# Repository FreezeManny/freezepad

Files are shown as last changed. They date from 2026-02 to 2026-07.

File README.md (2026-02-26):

# Freezepad

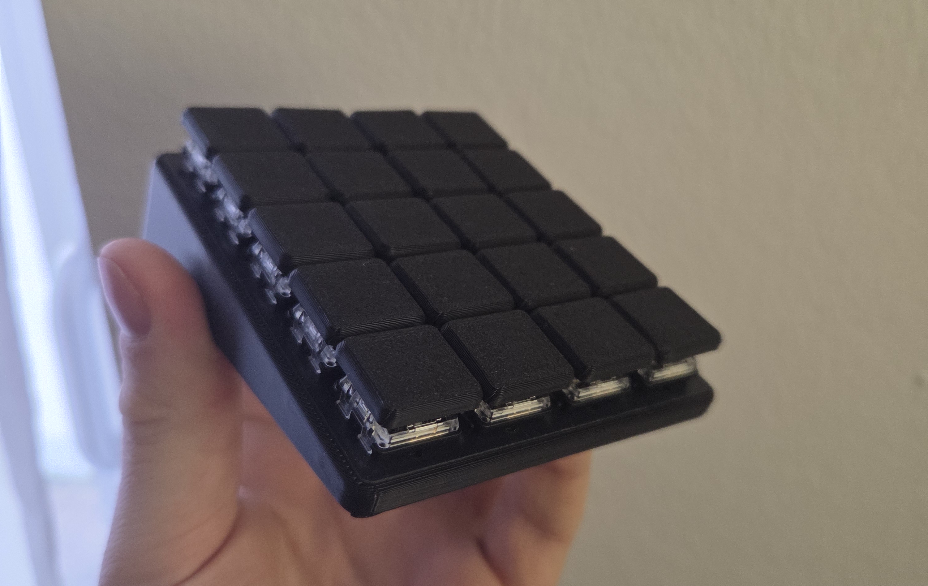
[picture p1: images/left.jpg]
Left

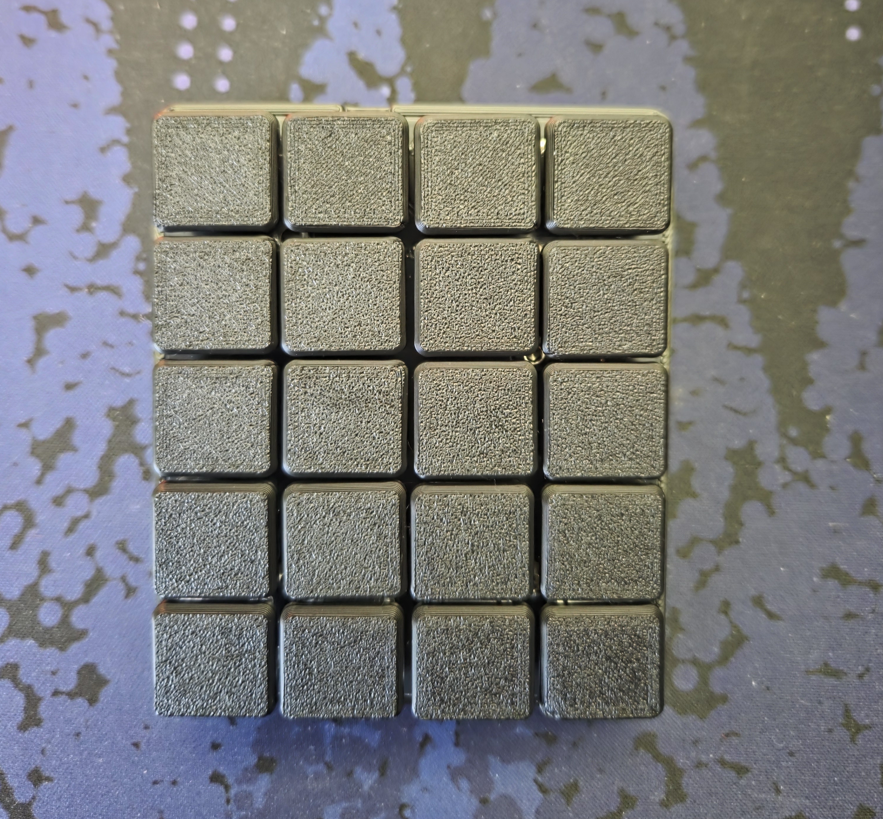
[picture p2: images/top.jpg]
Top


This repository contains all files and configuration for the **Freezepad**, a custom wireless 20-key (5×4) low-profile macropad built completely from scratch. The goal was to create the smallest possible macropad footprint — achieved by placing the Nice!Nano v2 controller directly below the switches and eliminating diodes entirely. It runs ZMK firmware and is housed in a custom 3D printed case.

## Table of Contents

- [Hardware Components](#hardware-components)
- [PCB](#pcb)
- [Firmware (ZMK)](#firmware-zmk)
- [3D Printed Case](#3d-printed-case)
- [Build Notes](#build-notes)

---

## Hardware Components

| Component | Item | Notes |
| :--- | :--- | :--- |
| **PCB** | Custom Freezepad PCB | Ordered from JLCPCB. Files in `/pcb/`. |
| **Small Electronics** | 1x Push Button 6x2mm, 20x Kailh Choc V1 Hotswap Sockets, 1x Battery Switch | Ordered from AliExpress. |
| **Small Case Parts** | 3x M3 Heat Insert, 3x M3 Screw | For securing the PCB to the case. |
| **Controller** | 1x Nice!Nano v2 (or compatible) | Wireless connectivity via Bluetooth. |
| **Battery** | 1x 102050 LiPo (1000mAh) | Fits in the custom case. |
| **Switches** | 20x Kailh Choc V1 | e.g., Sunset, Robins. |
| **Keycaps** | 20x Choc V1 Keycaps | e.g., MBK Blank Choc Keycaps. |
| **Case** | Custom 3D Printed Case | Files are located in the `/case` directory. |

---

## PCB

The custom PCB was designed using Ergogen. The files are located in the `/pcb/` directory.

---

## Firmware (ZMK)

The Freezepad runs on [ZMK Firmware](https://zmk.dev/docs), designed for wireless keyboards and macropads.

### Configuration

* **ZMK Config:** The main configuration files are located in the `/config/` directory.

### Configure, Build & Flash

* **Configuration:** Use the [Keymap Editor](https://nickcoutsos.github.io/keymap-editor/)
* **Build:** Standard GitHub Actions (see `build.yaml`)
* **Flash:** Consult the [Nice!Nano documentation](https://nicekeyboards.com/docs/nice-nano/)

---

## 3D Printed Case

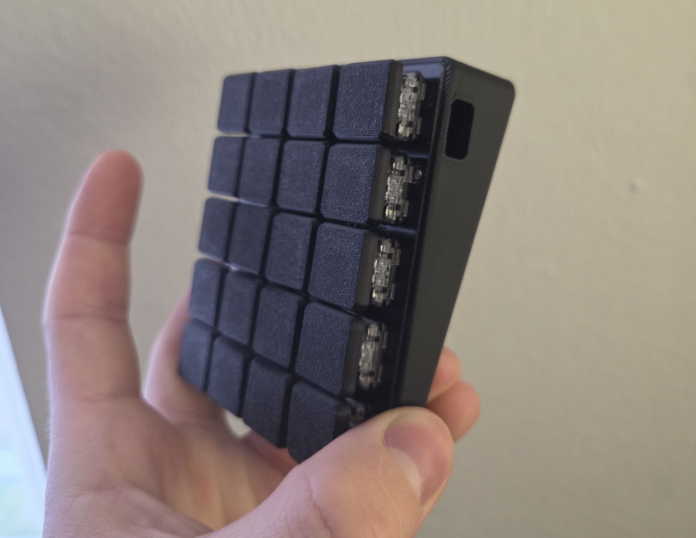
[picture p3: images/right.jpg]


A custom case designed in Fusion360. Source and STEP files are provided in `/case`.

### Recommended Print Settings

* **Material:** ABS / ASA / PETG preferred for better heat resistance
* **Outer Walls:** Minimum of 3
* **Layer Height:** 0.2mm
* **Infill:** 15–20%
* **Supports:** Not required

---

## Build Notes
* **ControllerPlacement:** The Controller sits under the switches. Ensure that you trim the soldered Pins flush, otherwise swtiches will not plug in flush.
* **Battery Switch:** The battery switch is mounted on the PCB and accessible from the side of the case.

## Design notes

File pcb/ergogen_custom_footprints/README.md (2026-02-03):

Custom footprints ripped from the abyss https://github.com/kvietcong/the-abyss 

Adjusted for My Design (f.e. pin 32 and 33 removal)

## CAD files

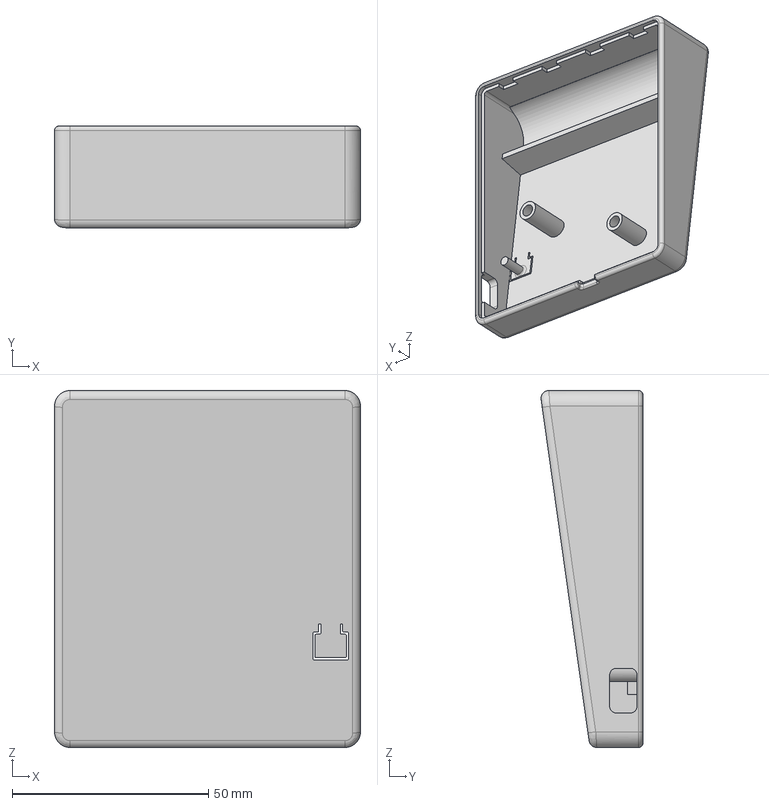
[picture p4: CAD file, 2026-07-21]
case/Case18650.step
78.0 x 26.0 x 91.0 mm

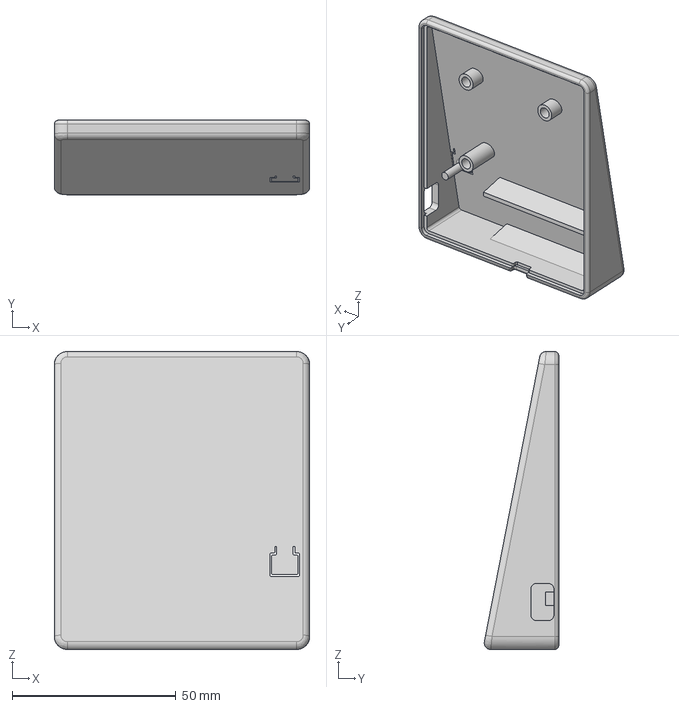
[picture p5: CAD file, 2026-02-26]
case/Case.step
78.0 x 22.8 x 91.0 mm

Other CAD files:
case/Case.f3z
case/Case.stl
case/Case18650.f3z
case/Case18650.stl

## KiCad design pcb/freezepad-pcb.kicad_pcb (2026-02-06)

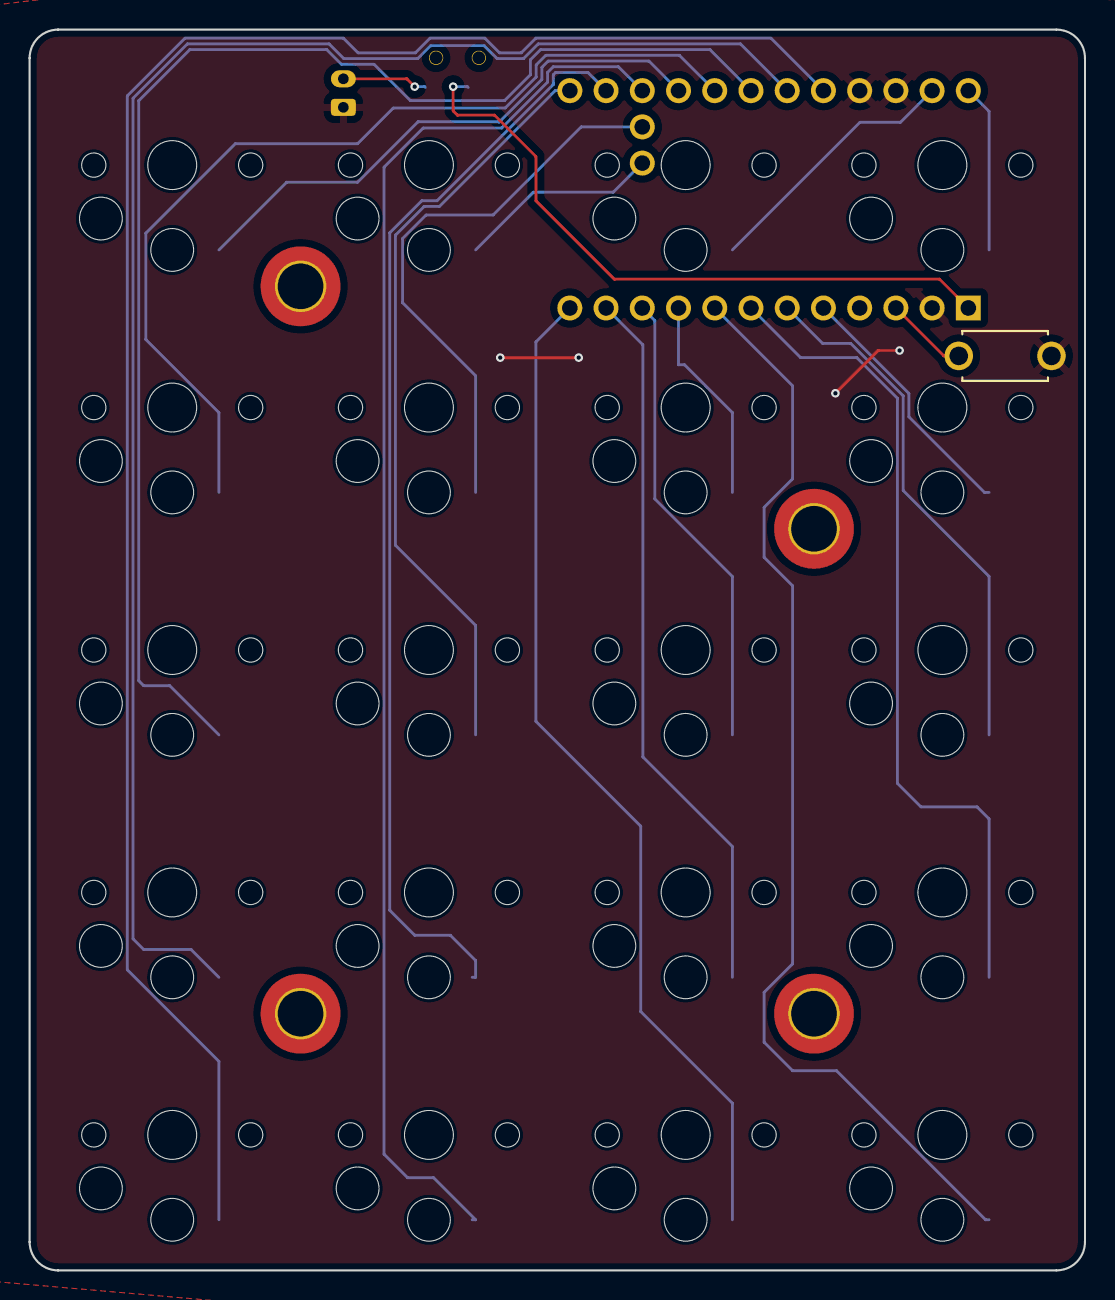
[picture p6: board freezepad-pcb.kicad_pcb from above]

Board: 2 copper layers, 74.0 x 87.0 mm, 24 parts (1 on the bottom side), 24 nets.

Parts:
B1: ResetSW
JST1: battery_connector_jst_ph_2
MCU1: ProMicro
S1, S2, S3, S4, S5, S6, S7, S8, S9, S10, S11, S12, S13, S14, S15, S16, S17, S18, S19, S20: PG1350
T1: SPDT_C128955

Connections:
B+: JST1.2, T1.1
GND: B1.2, JST1.1, MCU1.2, MCU1.15, MCU1.16, S1.2, S2.2, S3.2, S4.2, S5.2, S6.2, S7.2, S8.2, S9.2, S10.2, S11.2, S12.2, S13.2, S14.2, S15.2, S16.2, S17.2, S18.2, S19.2, S20.2
RAW: MCU1.1, T1.2
RST: B1.1, MCU1.3
matrix_col1_row1: MCU1.17, S1.1
matrix_col1_row2: MCU1.18, S2.1
matrix_col1_row3: MCU1.19, S3.1
matrix_col1_row4: MCU1.20, S4.1
matrix_col1_row5: MCU1.21, S5.1
matrix_col2_row1: MCU1.22, S6.1
matrix_col2_row2: MCU1.23, S7.1
matrix_col2_row3: MCU1.24, S8.1
matrix_col2_row4: MCU1.31, S9.1
matrix_col2_row5: MCU1.32, S10.1
matrix_col3_row1: MCU1.12, S11.1
matrix_col3_row2: MCU1.11, S12.1
matrix_col3_row3: MCU1.10, S13.1
matrix_col3_row4: MCU1.9, S14.1
matrix_col3_row5: MCU1.14, S15.1
matrix_col4_row1: MCU1.8, S16.1
matrix_col4_row2: MCU1.7, S17.1
matrix_col4_row3: MCU1.6, S18.1
matrix_col4_row4: MCU1.5, S19.1
matrix_col4_row5: MCU1.13, S20.1

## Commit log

2026-02-03 Added Footprints
2026-02-03 Rename PCB configuration to freezepad-pcb and set template to kicad8
2026-02-03 Refactor PCB configuration and remove Nice!Nano footprint
    - Updated the PCB configuration in freezepad-egrogen.yaml:
    - Added anchor shift for matrix centering.
    - Changed controller reference from 'ceoloide/mcu_nice_nano' to 'nicenano'.
    - Adjusted pin mappings for the controller to align with new configuration.
    - Removed unnecessary pin assignments for row 5.
    - Updated reset button component reference.
    - Deleted the Nice!Nano footprint JavaScript file as it is no longer needed.
2026-02-03 First sketch of updated Pin Mapping
2026-02-03 Added first layouted PCB
    [freezepad-pcb.kicad_pcb]
2026-02-03 Added Routing
    [freezepad-pcb.kicad_pcb]
2026-02-06 Add .gitignore for KiCad project files and temporary files
2026-02-06 Add initial KiCad project file for Freezepad PCB design
    - Created freezepad-pcb.kicad_pro with default design settings
    - Configured design rules, dimensions, and layer settings
    - Established net settings and IPC2581 metadata
    - Included teardrop and tuning pattern settings for enhanced routing
    [freezepad-pcb.kicad_pcb]
2026-02-06 Moved and removed Text Added ZMK
    [freezepad-pcb.kicad_pcb]
2026-02-06 feat: add Freezepad keyboard configuration and layout
    - Removed the existing 'the_abyss.yml' configuration file.
    - Added GitHub Actions workflow for building ZMK firmware.
    - Created build.yaml for GitHub Actions matrix configuration.
    - Introduced Kconfig.defconfig for Freezepad keyboard name.
    - Added freezepad-layouts.dtsi for physical layout definitions.
    - Created freezepad.conf for Freezepad configuration settings.
    - Implemented freezepad.dtsi for keyscan setup and layout mapping.
    - Added freezepad.overlay to include the Freezepad device tree.
    - Created freezepad.keymap with key bindings and layers.
    - Added info.json for Freezepad layout metadata.
    - Introduced west.yml for managing ZMK fir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
    [freezepad-pcb.kicad_pcb]
2026-02-19 feat: update keymap bindings for FlightSim layer and adjust PCB step file pathu
2026-02-19 Tried fix for Pin 102
2026-02-26 Added Case files
    [Case.f3z, Case.step, Case.stl]
2026-07-21 add case
    [Case18650.f3z, Case18650.step, Case18650.stl]
